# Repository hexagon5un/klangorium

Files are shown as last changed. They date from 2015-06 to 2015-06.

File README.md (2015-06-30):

# The Klangorium
Hardware and tutorials for the Hackaday / Logic Noise Klangorium demo board

Over on [Hackaday](https://www.hackaday.com), I've been writing a [series of articles](https://hackaday.com/tag/logic-noise/) on building up synthesizers out of 4000-series CMOS logic chips.  It's been great fun building them up on an breadboard and then tearing them back down, but after a while it's time to do something more permanent.

The result is this here Klangorium board.  

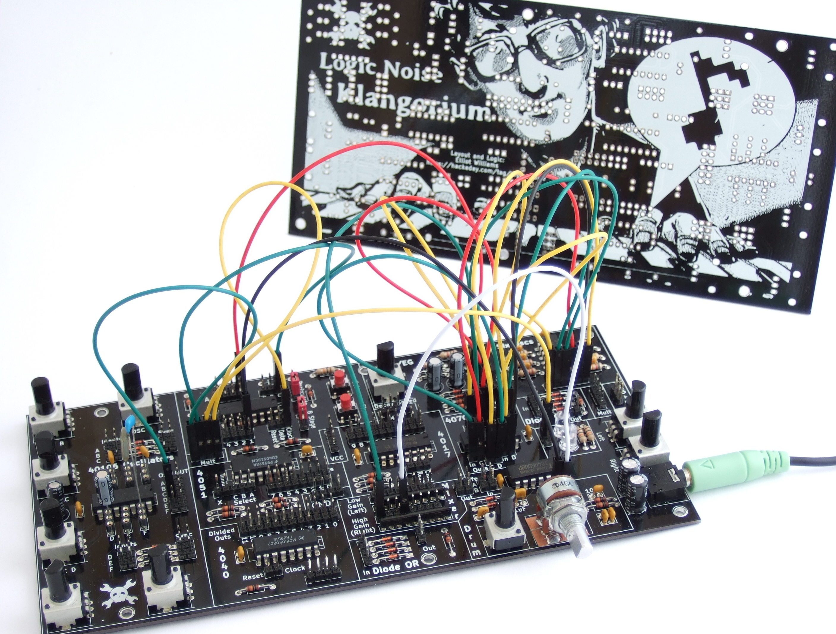
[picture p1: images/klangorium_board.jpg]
Board Money Shot


For a tutorial on how to use it, please head over to the [Hackaday.io](https://hackaday.io/project/6540-logic-noise-klangorium) page, or just start working through the [Logic Noise series](https://hackaday.com/tag/logic-noise/) from the beginning.  You'll find that it covers one module per session, and you'll learn a hell of a lot about ghetto synthesis and logic chips if you do.

## Getting One 

If you just want one, and can't wait for it to show up in kit form in the Hackaday shop, the production gerbers of version 1.0 are all zipped up [here](https://github.com/hexagon5un/klangorium/blob/master/kicad/gerbers/logic_noise_playground_elliot_williams.zip).  They're guaranteed to work with Elecrow, and will probably work for any other board manufacturer that's able to change the filename extensions if they need to.  

If you'd like to make your own, the design is entirely possible to do at home.  (I should know, I've built a couple prototypes.)  It's in Kicad, and designed with 16 mil traces and spacing, which is totally doable by toner transfer.  The only trick is that it's double-sided, but all you really have to do there is get the alignment right and pay attention to soldering the pin-headers to the top side when necessary.  And then drill something like 550 holes...  You probably want to get this one fabbed or wait until we have them for sale.

And if you'd just like to mess around with some of the circuit ideas, the kicad directory is for you!  The project is structured as a heirarchical schematic, and each module sits inside its own sub-sheet.  So if you just want the VCA/EG part of the board for a project of yours, it's in vca_eg.sch.  How easy is that?!

## Building One

Say you've got the board and parts in front of you.  Congrats!  Now put it together. 

It's not hard, but it's got 550 solder joints.  The good news is that none of them are particularly critical or difficult.  If you're a beginner with the soldering iron, you'll be experienced by the time you're done.  (Or you'll be driven stark-raving mad.)

I've built up a few of these now, and here's my advice.  

First, put all the header pins in their respective holes.  Now get a piece of cardboard and put it on top of the pins before you (gently) flip it over.  This way, you stand a chance of getting the pins aligned straight with the board upside-down.  Now solder in one pin from each header, to make it easy to adjust any that are screwy.  Only once you're content that they're all in straight, solder the headers in for real.  It's a lot of soldering.  Take a break.

Now you've got a lot of freedom of choice.  I'd start by completely populating and soldering the mixer/output section and then the six oscillators at the far left of the board.  You can have a lot of fun with just six voices.  See [the first Logic Noise column](https://hackaday.com/2015/02/04/logic-noise-sweet-sweet-oscillator-sounds/) for inspiration. 

And then keep following through the series, building out a new module one at a time and then working through the examples and playing around until you've got mastery of the parts.  I wrote the columns to build on each other, so if you follow along, you'll always have what you need for any of the examples already built up from previous columns.  

By the time you come to the end, you've reached Nirvana.  If you haven't had fun with the sequencer and Melody Generator circuits, I don't know what to say.  

And if you do pick this up and enjoy, let me know?

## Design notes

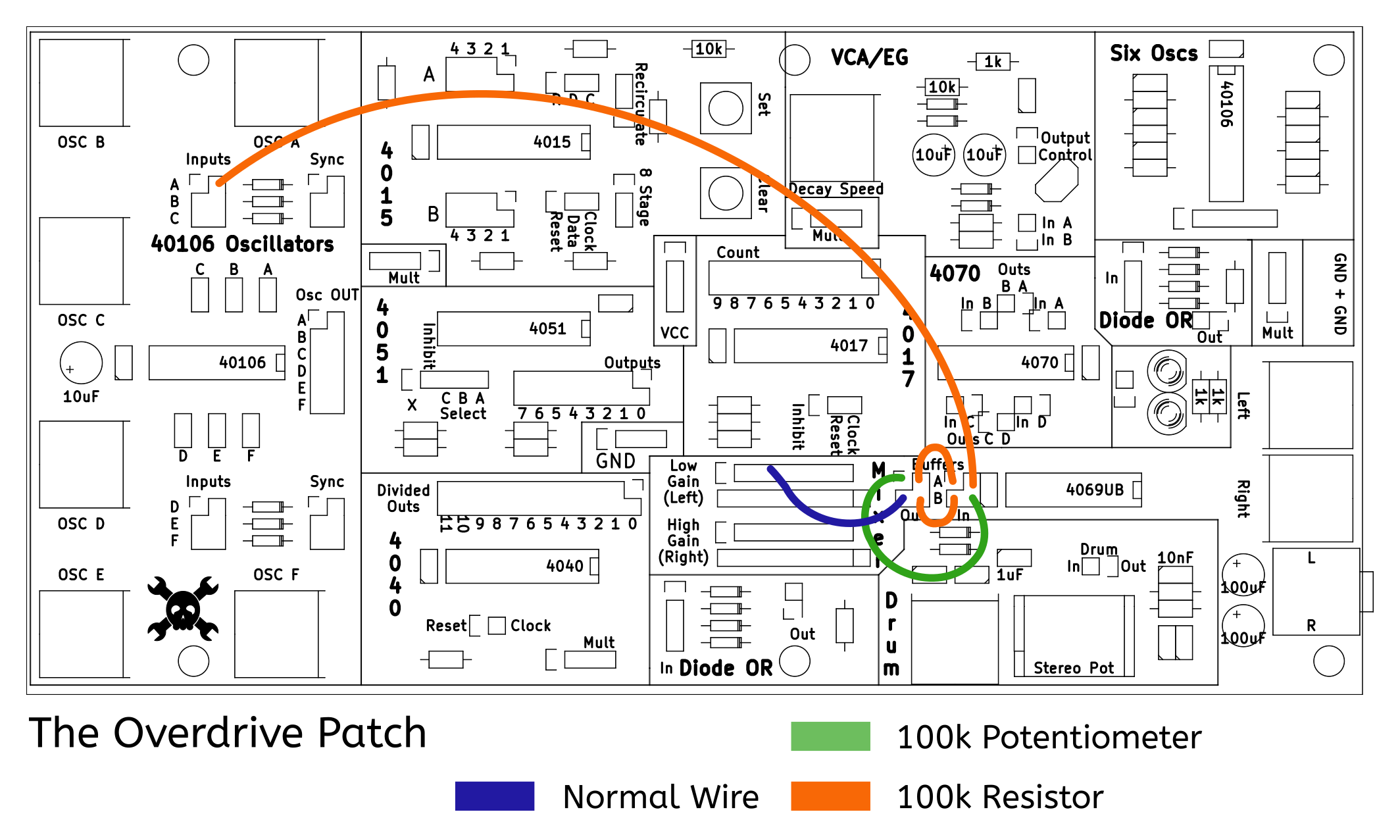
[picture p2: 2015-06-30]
images/patch_overdrive.png

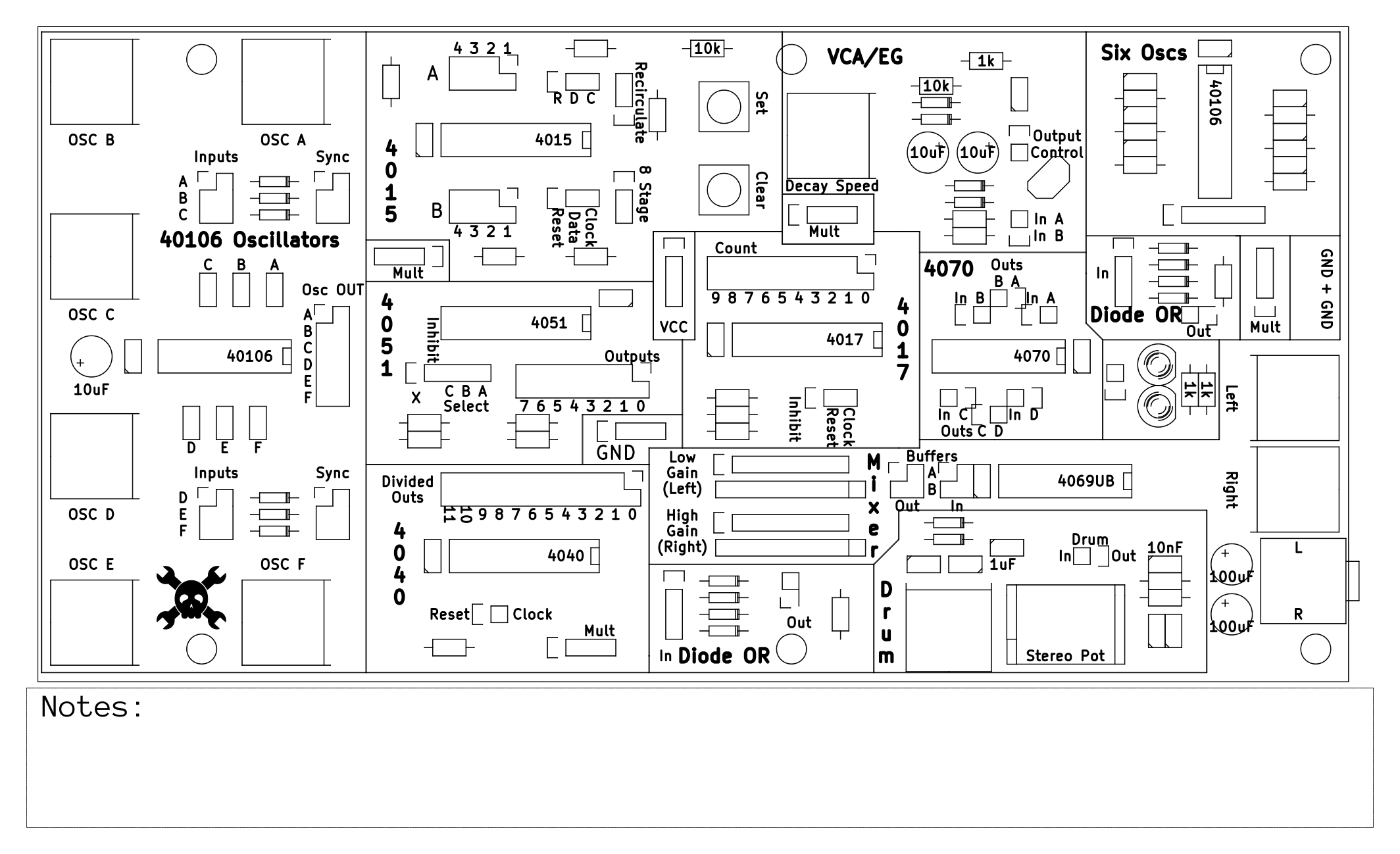
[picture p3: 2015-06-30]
images/patch_template.png

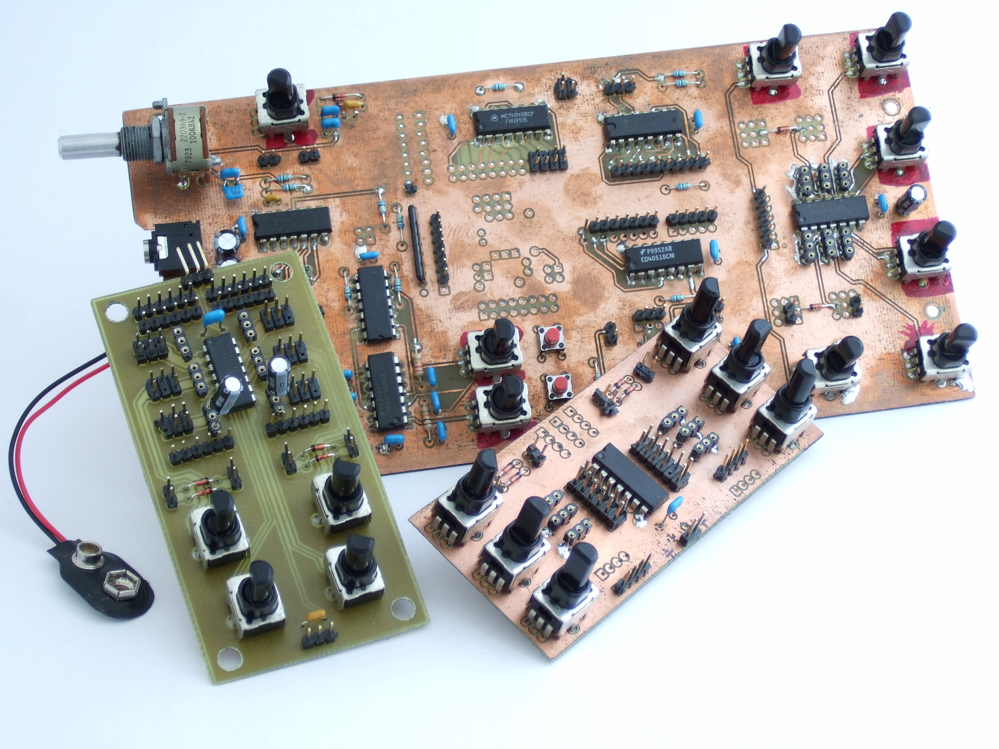
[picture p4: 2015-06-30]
images/klangorium_prototypes.jpg

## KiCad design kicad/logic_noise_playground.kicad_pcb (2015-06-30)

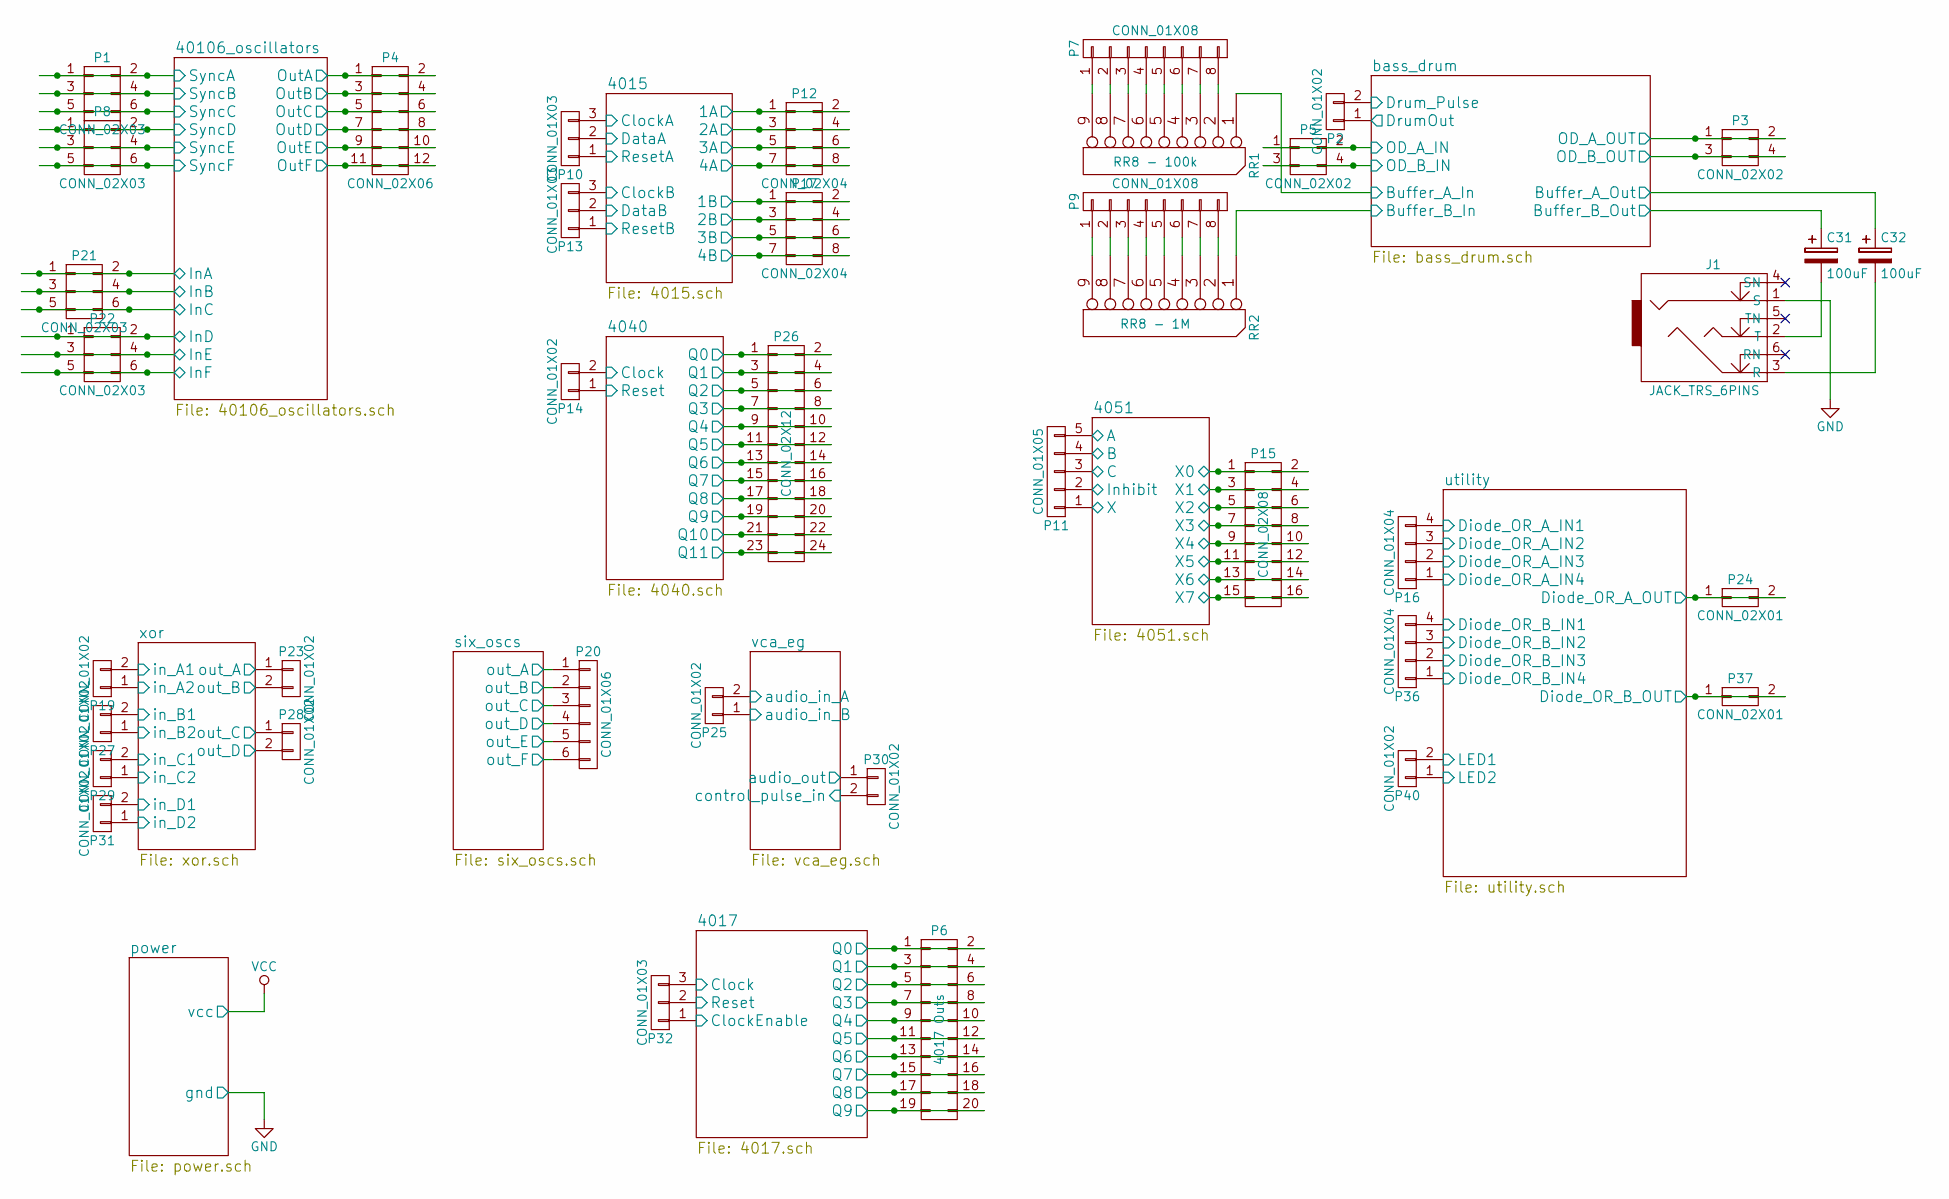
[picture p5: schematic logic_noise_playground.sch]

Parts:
C31, C32: 100uF; Elko_vert_11.2x6.3mm_RM2.5
J1: JACK_TRS_6PINS; stereo_jack
P1, P8, P21, P22: CONN_02X03; Pin_Header_Straight_2x03
P2, P14, P19, P23, P25, P27, P28, P29, P30, P31, P40: CONN_01X02; Pin_Header_Straight_1x02
P3, P5: CONN_02X02; Pin_Header_Straight_2x02
P4: CONN_02X06; Pin_Header_Straight_2x06
P6: 4017 Outs; Pin_Header_Straight_2x10
P7, P9: CONN_01X08; Pin_Header_Straight_1x08
P10, P13, P32: CONN_01X03; Pin_Header_Straight_1x03
P11: CONN_01X05; Pin_Header_Straight_1x05
P12, P17: CONN_02X04; Pin_Header_Straight_2x04
P15: CONN_02X08; Pin_Header_Straight_2x08
P16, P36: CONN_01X04; Pin_Header_Straight_1x04
P20: CONN_01X06; Pin_Header_Straight_1x06
P24, P37: CONN_02X01; Pin_Header_Straight_2x01
P26: CONN_02X12; Pin_Header_Straight_2x12
RR1: RR8 - 100k; r_pack8
RR2: RR8 - 1M; r_pack8

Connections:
/4015/1A: P12.1, P12.2; also elsewhere on the board
/4015/1B: P17.1, P17.2; also elsewhere on the board
/4015/2A: P12.3, P12.4; also elsewhere on the board
/4015/2B: P17.3, P17.4; also elsewhere on the board
/4015/3A: P12.5, P12.6; also elsewhere on the board
/4015/3B: P17.5, P17.6; also elsewhere on the board
/4015/4A: P12.7, P12.8; also elsewhere on the board
/4015/4B: P17.7, P17.8; also elsewhere on the board
/4015/ClockA: P10.3; also elsewhere on the board
/4015/ClockB: P13.3; also elsewhere on the board
/4015/DataA: P10.2; also elsewhere on the board
/4015/DataB: P13.2; also elsewhere on the board
/4015/ResetA: P10.1; also elsewhere on the board
/4015/ResetB: P13.1; also elsewhere on the board
/4017/Clock: P32.3; also elsewhere on the board
/4017/ClockEnable: P32.1; also elsewhere on the board
/4017/Q0: P6.1, P6.2; also elsewhere on the board
/4017/Q1: P6.3, P6.4; also elsewhere on the board
/4017/Q2: P6.5, P6.6; also elsewhere on the board
/4017/Q3: P6.7, P6.8; also elsewhere on the board
/4017/Q4: P6.9, P6.10; also elsewhere on the board
/4017/Q5: P6.11, P6.12; also elsewhere on the board
/4017/Q6: P6.13, P6.14; also elsewhere on the board
/4017/Q7: P6.15, P6.16; also elsewhere on the board
/4017/Q8: P6.17, P6.18; also elsewhere on the board
/4017/Q9: P6.19, P6.20; also elsewhere on the board
/4017/Reset: P32.2; also elsewhere on the board
/4040/Clock: P14.2; also elsewhere on the board
/4040/Q0: P26.1, P26.2; also elsewhere on the board
/4040/Q1: P26.3, P26.4; also elsewhere on the board
/4040/Q2: P26.5, P26.6; also elsewhere on the board
/4040/Q3: P26.7, P26.8; also elsewhere on the board
/4040/Q4: P26.9, P26.10; also elsewhere on the board
/4040/Q5: P26.11, P26.12; also elsewhere on the board
/4040/Q6: P26.13, P26.14; also elsewhere on the board
/4040/Q7: P26.15, P26.16; also elsewhere on the board
/4040/Q8: P26.17, P26.18; also elsewhere on the board
/4040/Q9: P26.19, P26.20; also elsewhere on the board
/4040/Q10: P26.21, P26.22; also elsewhere on the board
/4040/Q11: P26.23, P26.24; also elsewhere on the board
/4040/Reset: P14.1; also elsewhere on the board
/4051/A: P11.5; also elsewhere on the board
/4051/B: P11.4; also elsewhere on the board
/4051/C: P11.3; also elsewhere on the board
/4051/Inhibit: P11.2; also elsewhere on the board
/4051/X: P11.1; also elsewhere on the board
/4051/X0: P15.1, P15.2; also elsewhere on the board
/4051/X1: P15.3, P15.4; also elsewhere on the board
/4051/X2: P15.5, P15.6; also elsewhere on the board
/4051/X3: P15.7, P15.8; also elsewhere on the board
/4051/X4: P15.9, P15.10; also elsewhere on the board
/4051/X5: P15.11, P15.12; also elsewhere on the board
/4051/X6: P15.13, P15.14; also elsewhere on the board
/4051/X7: P15.15, P15.16; also elsewhere on the board
/40106_oscillators/InA: P21.1, P21.2; also elsewhere on the board
/40106_oscillators/InB: P21.3, P21.4; also elsewhere on the board
/40106_oscillators/InC: P21.5, P21.6; also elsewhere on the board
/40106_oscillators/InD: P22.1, P22.2; also elsewhere on the board
/40106_oscillators/InE: P22.3, P22.4; also elsewhere on the board
/40106_oscillators/InF: P22.5, P22.6; also elsewhere on the board
/40106_oscillators/OutA: P4.1, P4.2; also elsewhere on the board
/40106_oscillators/OutB: P4.3, P4.4; also elsewhere on the board
/40106_oscillators/OutC: P4.5, P4.6; also elsewhere on the board
/40106_oscillators/OutD: P4.7, P4.8; also elsewhere on the board
/40106_oscillators/OutE: P4.9, P4.10; also elsewhere on the board
/40106_oscillators/OutF: P4.11, P4.12; also elsewhere on the board
/40106_oscillators/SyncA: P1.1, P1.2; also elsewhere on the board
/40106_oscillators/SyncB: P1.3, P1.4; also elsewhere on the board
/40106_oscillators/SyncC: P1.5, P1.6; also elsewhere on the board
/40106_oscillators/SyncD: P8.1, P8.2; also elsewhere on the board
/40106_oscillators/SyncE: P8.3, P8.4; also elsewhere on the board
/40106_oscillators/SyncF: P8.5, P8.6; also elsewhere on the board
/bass_drum/Buffer_A_In: RR1.1 (COM); also elsewhere on the board
/bass_drum/Buffer_A_Out: C32.1; also elsewhere on the board
/bass_drum/Buffer_B_In: RR2.1 (COM); also elsewhere on the board
/bass_drum/Buffer_B_Out: C31.1; also elsewhere on the board
/bass_drum/DrumOut: P2.1; also elsewhere on the board
/bass_drum/Drum_Pulse: P2.2; also elsewhere on the board
/bass_drum/OD_A_IN: P5.1, P5.2; also elsewhere on the board
/bass_drum/OD_A_OUT: P3.1, P3.2; also elsewhere on the board
/bass_drum/OD_B_IN: P5.3, P5.4; also elsewhere on the board
/bass_drum/OD_B_OUT: P3.3, P3.4; also elsewhere on the board
/six_oscs/out_A: P20.1; also elsewhere on the board
/six_oscs/out_B: P20.2; also elsewhere on the board
/six_oscs/out_C: P20.3; also elsewhere on the board
/six_oscs/out_D: P20.4; also elsewhere on the board
/six_oscs/out_E: P20.5; also elsewhere on the board
/six_oscs/out_F: P20.6; also elsewhere on the board
/utility/Diode_OR_A_IN1: P16.4; also elsewhere on the board
/utility/Diode_OR_A_IN2: P16.3; also elsewhere on the board
/utility/Diode_OR_A_IN3: P16.2; also elsewhere on the board
/utility/Diode_OR_A_IN4: P16.1; also elsewhere on the board
/utility/Diode_OR_A_OUT: P24.1, P24.2; also elsewhere on the board
/utility/Diode_OR_B_IN1: P36.4; also elsewhere on the board
/utility/Diode_OR_B_IN2: P36.3; also elsewhere on the board
/utility/Diode_OR_B_IN3: P36.2; also elsewhere on the board
/utility/Diode_OR_B_IN4: P36.1; also elsewhere on the board
/utility/Diode_OR_B_OUT: P37.1, P37.2; also elsewhere on the board
/utility/LED1: P40.2; also elsewhere on the board
/utility/LED2: P40.1; also elsewhere on the board
/vca_eg/audio_in_A: P25.2; also elsewhere on the board
/vca_eg/audio_in_B: P25.1; also elsewhere on the board
/vca_eg/audio_out: P30.1; also elsewhere on the board
/vca_eg/control_pulse_in: P30.2; also elsewhere on the board
/xor/in_A1: P19.2; also elsewhere on the board
/xor/in_A2: P19.1; also elsewhere on the board
/xor/in_B1: P27.2; also elsewhere on the board
/xor/in_B2: P27.1; also elsewhere on the board
/xor/in_C1: P29.2; also elsewhere on the board
/xor/in_C2: P29.1; also elsewhere on the board
/xor/in_D1: P31.2; also elsewhere on the board
/xor/in_D2: P31.1; also elsewhere on the board
/xor/out_A: P23.1; also elsewhere on the board
/xor/out_B: P23.2; also elsewhere on the board
/xor/out_C: P28.1; also elsewhere on the board
/xor/out_D: P28.2; also elsewhere on the board
GND: J1.1 (S); also elsewhere on the board
unnamed: C31.2, J1.2 (T)
unnamed: C32.2, J1.3 (R)
unnamed: P7.1, RR1.9
unnamed: P7.2, RR1.8
unnamed: P7.3, RR1.7
unnamed: P7.4, RR1.6
unnamed: P7.5, RR1.5
unnamed: P7.6, RR1.4
unnamed: P7.7, RR1.3
unnamed: P7.8, RR1.2
unnamed: P9.1, RR2.9
unnamed: P9.2, RR2.8
unnamed: P9.3, RR2.7
unnamed: P9.4, RR2.6
unnamed: P9.5, RR2.5
unnamed: P9.6, RR2.4
unnamed: P9.7, RR2.3
unnamed: P9.8, RR2.2

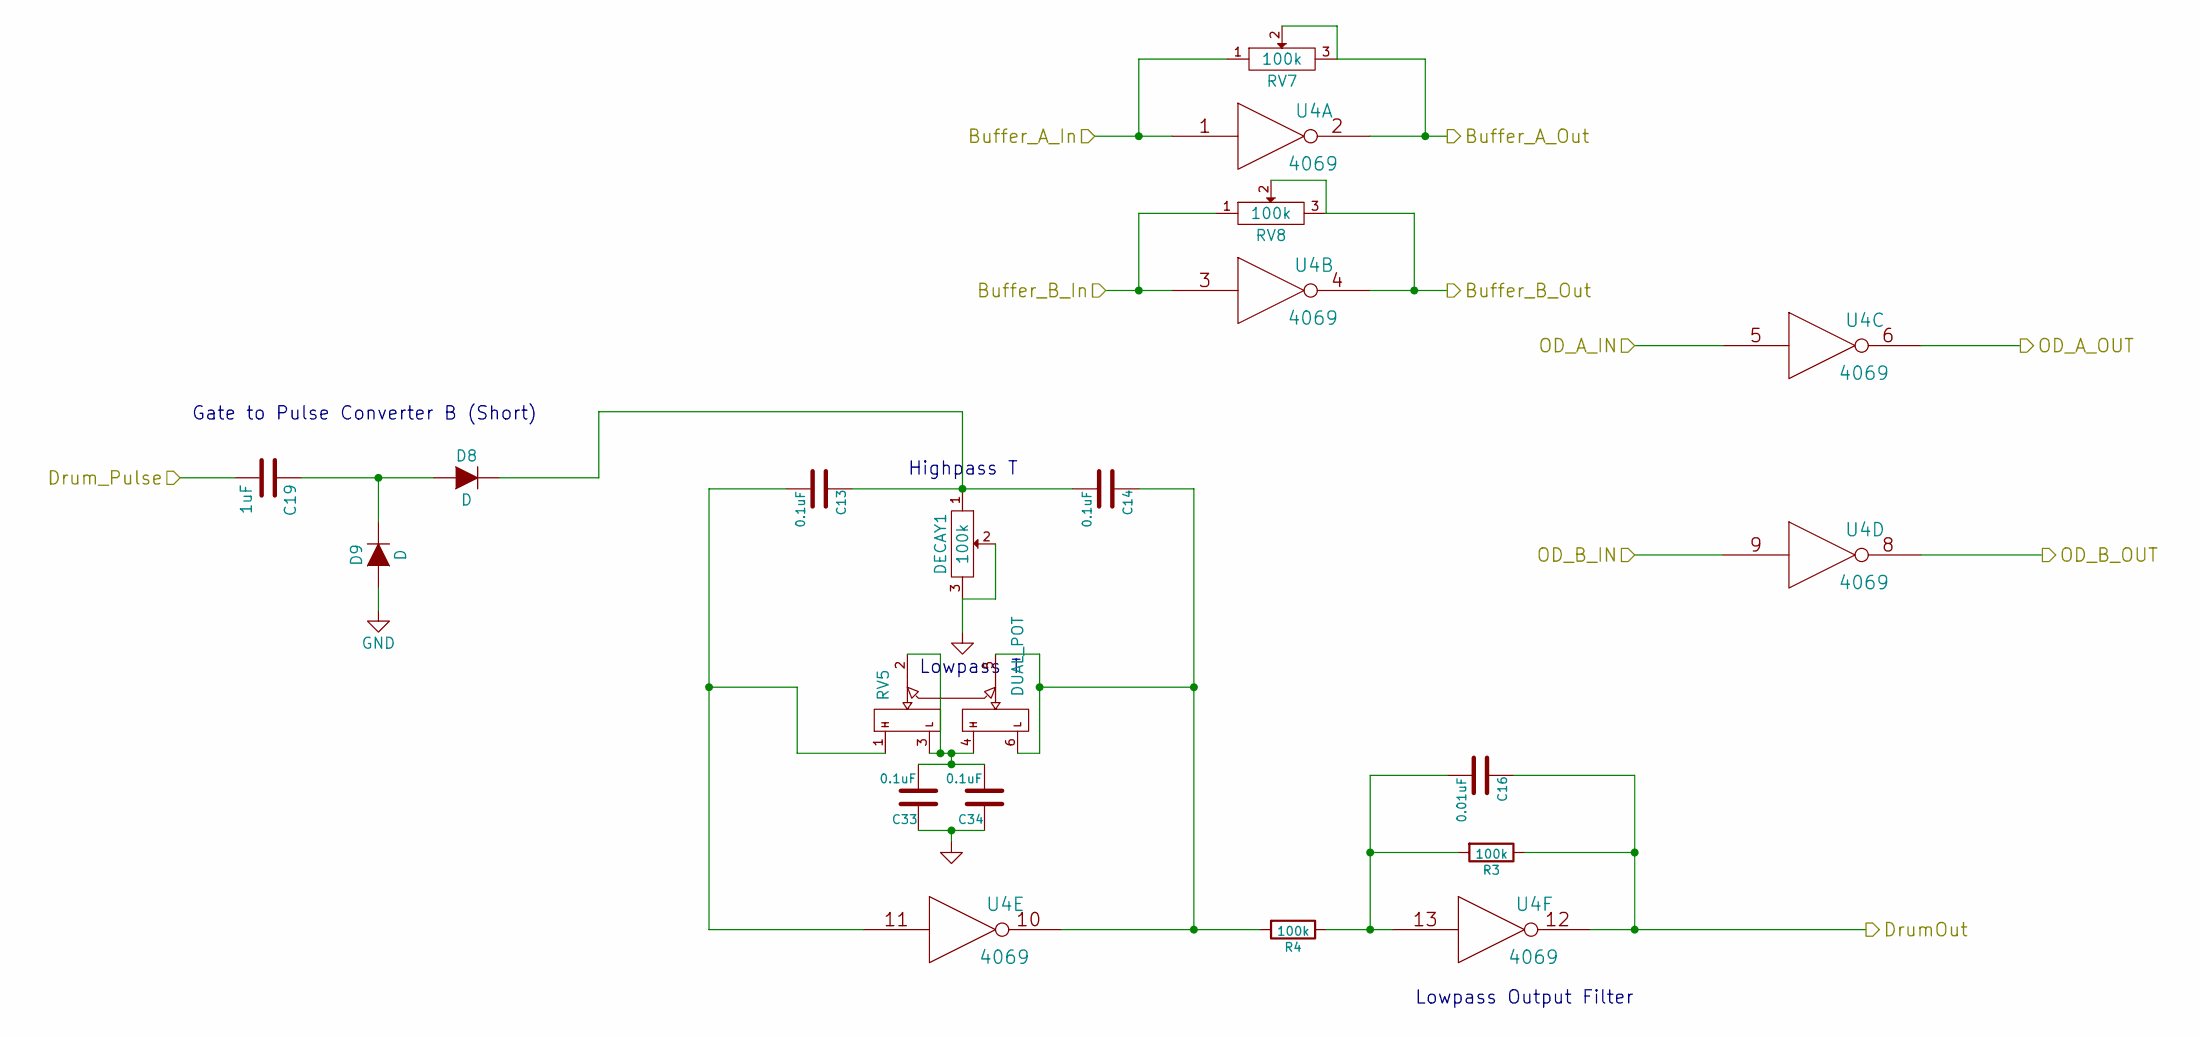
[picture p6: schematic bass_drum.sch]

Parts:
C13, C14, C33, C34: 0.1uF; C1
C16: 0.01uF; C1
C19: 1uF; C1
D8, D9: D; Diode_DO-35_SOD27_Horizontal_RM10
DECAY1: 100k; Potentiometer_9mm_vertical_pcb_mount
R3, R4: 100k; Resistor_Horizontal_RM10mm
RV5: DUAL_POT; Potentiometer_Alps-RK16-double
RV7, RV8: 100k; Potentiometer_9mm_vertical_pcb_mount
U4: 4069; DIP-14__300_ELL

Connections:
/bass_drum/Buffer_A_In: RV7.1, U4.1; also elsewhere on the board
/bass_drum/Buffer_A_Out: RV7.2, RV7.3, U4.2; also elsewhere on the board
/bass_drum/Buffer_B_In: RV8.1, U4.3; also elsewhere on the board
/bass_drum/Buffer_B_Out: RV8.2, RV8.3, U4.4; also elsewhere on the board
/bass_drum/DrumOut: C16.1, R3.1, U4.12; also elsewhere on the board
/bass_drum/Drum_Pulse: C19.2; also elsewhere on the board
/bass_drum/OD_A_IN: U4.5; also elsewhere on the board
/bass_drum/OD_A_OUT: U4.6; also elsewhere on the board
/bass_drum/OD_B_IN: U4.9; also elsewhere on the board
/bass_drum/OD_B_OUT: U4.8; also elsewhere on the board
GND: C33.1, C34.1, D9.1 (A), DECAY1.2, DECAY1.3, U4.7 (VSS); also elsewhere on the board
unnamed: C13.1, C14.2, D8.2 (K), DECAY1.1
unnamed: C13.2, RV5.1, U4.11
unnamed: C14.1, R4.2, RV5.5, RV5.6, U4.10
unnamed: C16.2, R3.2, R4.1, U4.13
unnamed: C19.1, D8.1 (A), D9.2 (K)
unnamed: C33.2, C34.2, RV5.2, RV5.3, RV5.4
VCC: U4.14 (VDD); also elsewhere on the board

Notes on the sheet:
Lowpass Output Filter
Highpass T
Lowpass T
Gate to Pulse Converter B (Short)

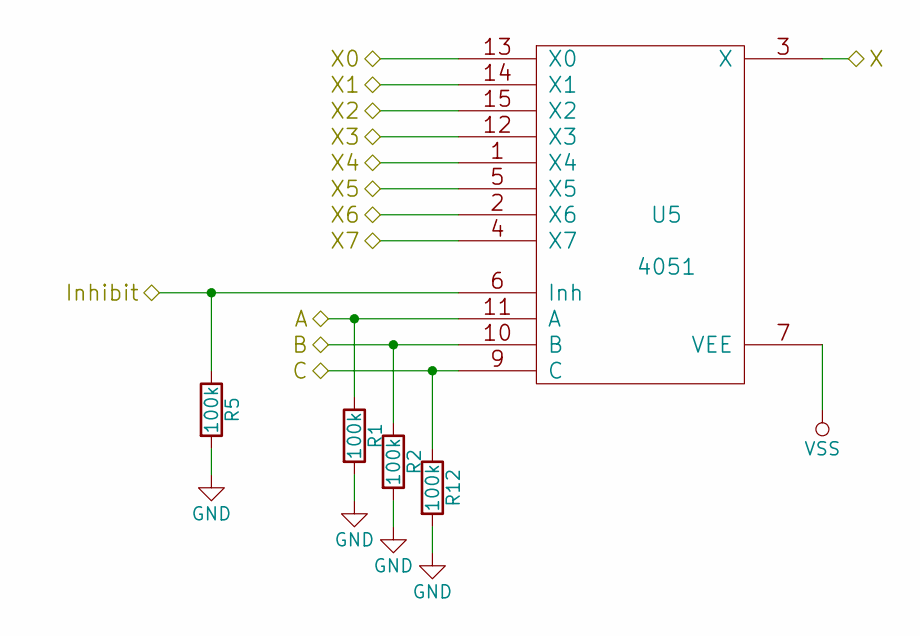
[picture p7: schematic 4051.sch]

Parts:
R1, R2, R5, R12: 100k; Resistor_Horizontal_RM10mm
U5: 4051; DIP-16__300_ELL

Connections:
/4051/A: R1.1, U5.11 (A); also elsewhere on the board
/4051/B: R2.1, U5.10 (B); also elsewhere on the board
/4051/C: R12.1, U5.9 (C); also elsewhere on the board
/4051/Inhibit: R5.1, U5.6 (Inh); also elsewhere on the board
/4051/X: U5.3 (X); also elsewhere on the board
/4051/X0: U5.13 (X0); also elsewhere on the board
/4051/X1: U5.14 (X1); also elsewhere on the board
/4051/X2: U5.15 (X2); also elsewhere on the board
/4051/X3: U5.12 (X3); also elsewhere on the board
/4051/X4: U5.1 (X4); also elsewhere on the board
/4051/X5: U5.5 (X5); also elsewhere on the board
/4051/X6: U5.2 (X6); also elsewhere on the board
/4051/X7: U5.4 (X7); also elsewhere on the board
GND: R1.2, R2.2, R5.2, R12.2, U5.7 (VEE), U5.8 (VSS); also elsewhere on the board
VCC: U5.16 (VDD); also elsewhere on the board

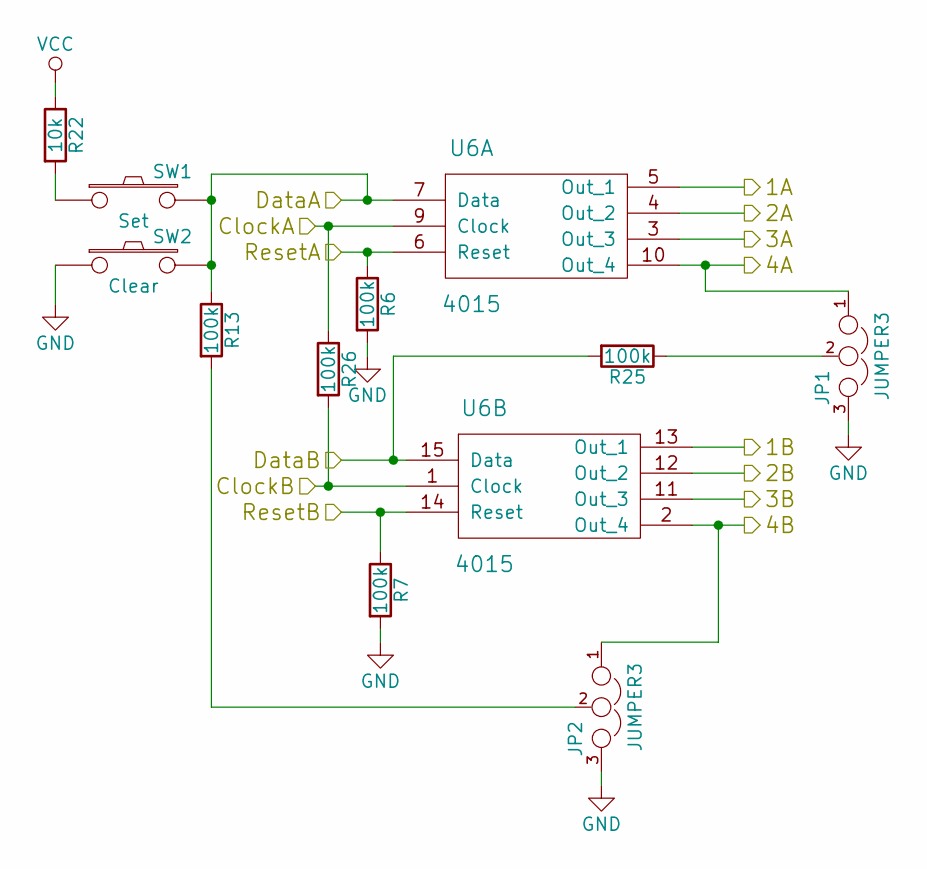
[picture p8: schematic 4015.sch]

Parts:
JP1, JP2: JUMPER3; Socket_Strip_Straight_1x03
R6, R7, R13, R25, R26: 100k; Resistor_Horizontal_RM10mm
R22: 10k; Resistor_Horizontal_RM10mm
SW1: Set; SW_PUSH_SMALL
SW2: Clear; SW_PUSH_SMALL
U6: 4015; DIP-16__300_ELL

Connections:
/4015/1A: U6.5 (Out_1); also elsewhere on the board
/4015/1B: U6.13 (Out_1); also elsewhere on the board
/4015/2A: U6.4 (Out_2); also elsewhere on the board
/4015/2B: U6.12 (Out_2); also elsewhere on the board
/4015/3A: U6.3 (Out_3); also elsewhere on the board
/4015/3B: U6.11 (Out_3); also elsewhere on the board
/4015/4A: JP1.1, U6.10 (Out_4); also elsewhere on the board
/4015/4B: JP2.1, U6.2 (Out_4); also elsewhere on the board
/4015/ClockA: R26.1, U6.9 (Clock); also elsewhere on the board
/4015/ClockB: R26.2, U6.1 (Clock); also elsewhere on the board
/4015/DataA: R13.1, SW1.2, SW2.2, U6.7 (Data); also elsewhere on the board
/4015/DataB: R25.2, U6.15 (Data); also elsewhere on the board
/4015/ResetA: R6.1, U6.6 (Reset); also elsewhere on the board
/4015/ResetB: R7.1, U6.14 (Reset); also elsewhere on the board
GND: JP1.3, JP2.3, R6.2, R7.2, SW2.1, U6.8 (VSS); also elsewhere on the board
unnamed: JP1.2, R25.1
unnamed: JP2.2, R13.2
unnamed: R22.2, SW1.1
VCC: R22.1, U6.16 (VDD); also elsewhere on the board

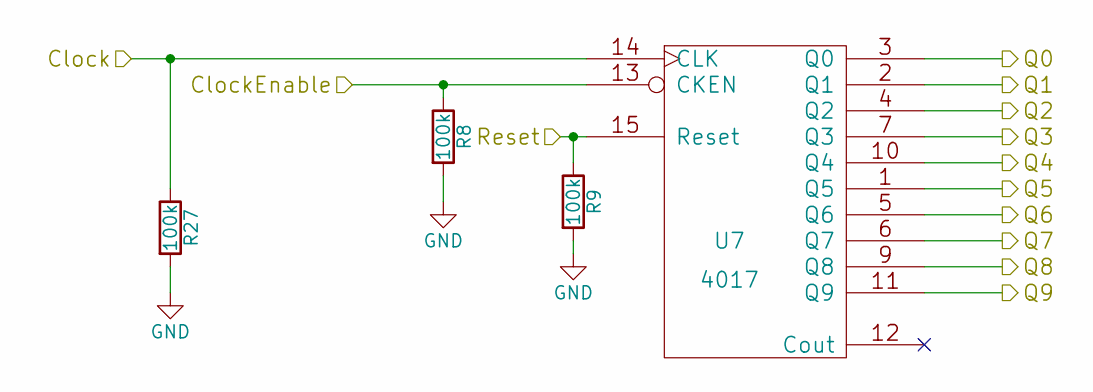
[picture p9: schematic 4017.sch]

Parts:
R8, R9, R27: 100k; Resistor_Horizontal_RM10mm
U7: 4017; DIP-16__300_ELL

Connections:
/4017/Clock: R27.1, U7.14 (CLK); also elsewhere on the board
/4017/ClockEnable: R8.1, U7.13 (CKEN); also elsewhere on the board
/4017/Q0: U7.3 (Q0); also elsewhere on the board
/4017/Q1: U7.2 (Q1); also elsewhere on the board
/4017/Q2: U7.4 (Q2); also elsewhere on the board
/4017/Q3: U7.7 (Q3); also elsewhere on the board
/4017/Q4: U7.10 (Q4); also elsewhere on the board
/4017/Q5: U7.1 (Q5); also elsewhere on the board
/4017/Q6: U7.5 (Q6); also elsewhere on the board
/4017/Q7: U7.6 (Q7); also elsewhere on the board
/4017/Q8: U7.9 (Q8); also elsewhere on the board
/4017/Q9: U7.11 (Q9); also elsewhere on the board
/4017/Reset: R9.1, U7.15 (Reset); also elsewhere on the board
GND: R8.2, R9.2, R27.2, U7.8 (VSS); also elsewhere on the board
VCC: U7.16 (VDD); also elsewhere on the board

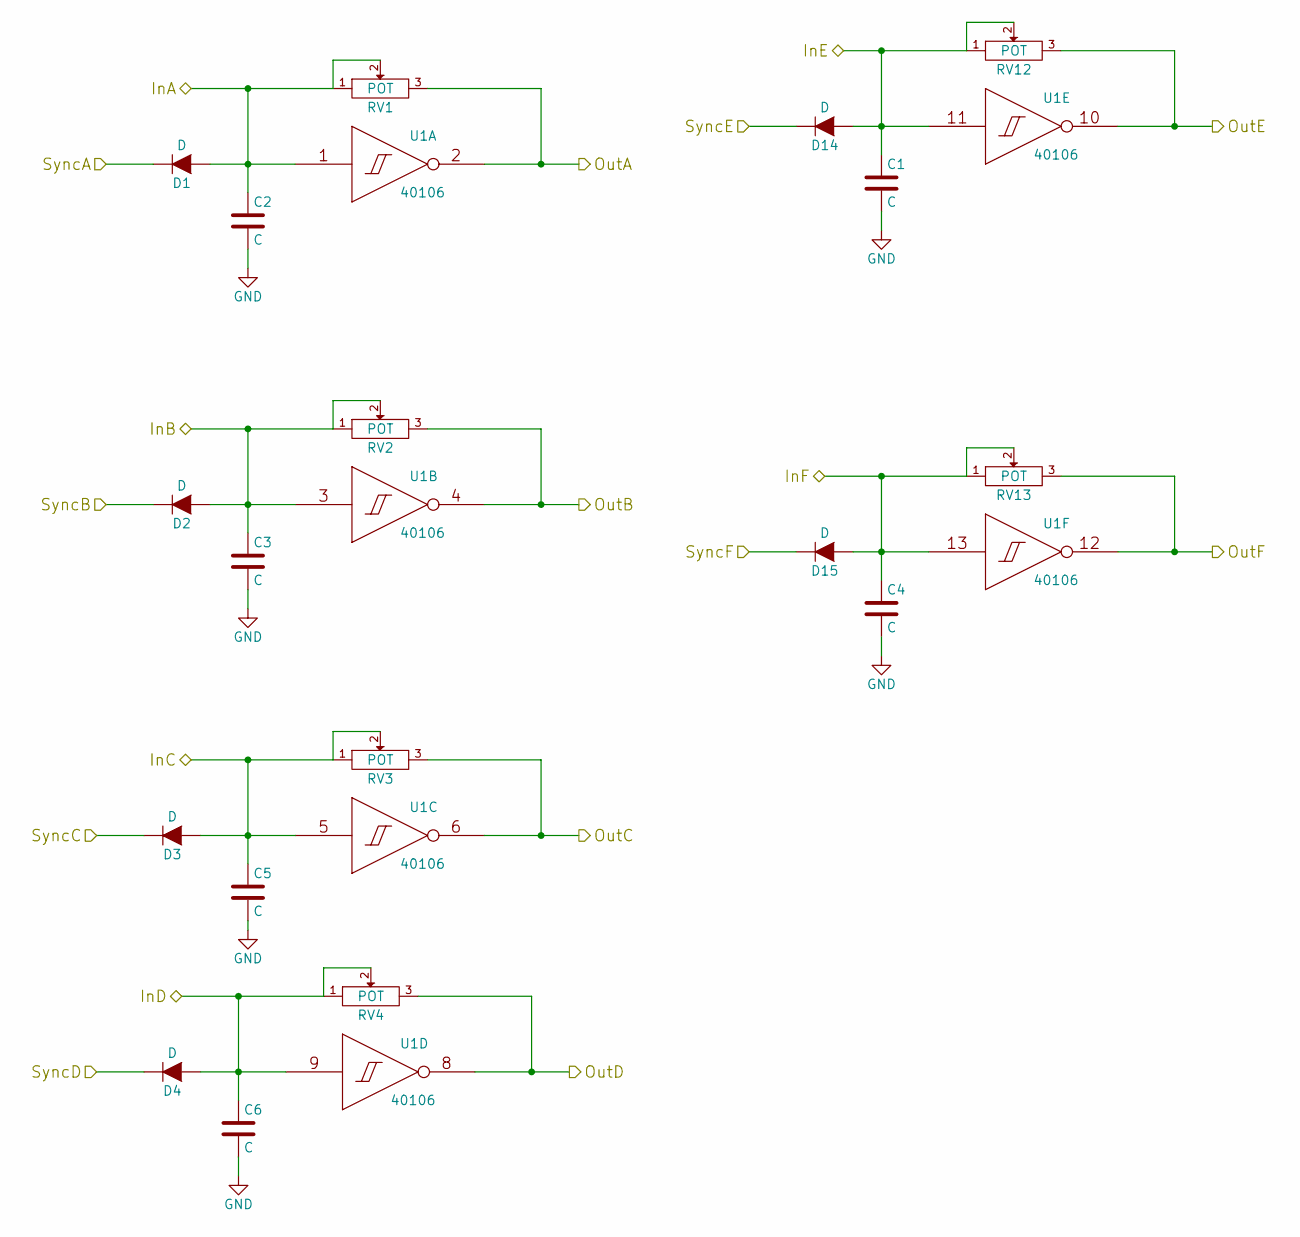
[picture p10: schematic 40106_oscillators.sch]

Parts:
C1, C2, C3, C4, C5, C6: C; cap_2+3
D1, D2, D3, D4, D14, D15: D; Diode_DO-35_SOD27_Horizontal_RM10
RV1, RV2, RV3, RV4, RV12, RV13: POT; Potentiometer_9mm_vertical_pcb_mount
U1: 40106; DIP-14__300_ELL

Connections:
/40106_oscillators/InA: C2.1, D1.1 (A), RV1.1, RV1.2, U1.1 (In); also elsewhere on the board
/40106_oscillators/InB: C3.1, D2.1 (A), RV2.1, RV2.2, U1.3 (In); also elsewhere on the board
/40106_oscillators/InC: C5.1, D3.1 (A), RV3.1, RV3.2, U1.5 (In); also elsewhere on the board
/40106_oscillators/InD: C6.1, D4.1 (A), RV4.1, RV4.2, U1.9 (In); also elsewhere on the board
/40106_oscillators/InE: C1.1, D14.1 (A), RV12.1, RV12.2, U1.11 (In); also elsewhere on the board
/40106_oscillators/InF: C4.1, D15.1 (A), RV13.1, RV13.2, U1.13 (In); also elsewhere on the board
/40106_oscillators/OutA: RV1.3, U1.2 (Out); also elsewhere on the board
/40106_oscillators/OutB: RV2.3, U1.4 (Out); also elsewhere on the board
/40106_oscillators/OutC: RV3.3, U1.6 (Out); also elsewhere on the board
/40106_oscillators/OutD: RV4.3, U1.8 (Out); also elsewhere on the board
/40106_oscillators/OutE: RV12.3, U1.10 (Out); also elsewhere on the board
/40106_oscillators/OutF: RV13.3, U1.12 (Out); also elsewhere on the board
/40106_oscillators/SyncA: D1.2 (K); also elsewhere on the board
/40106_oscillators/SyncB: D2.2 (K); also elsewhere on the board
/40106_oscillators/SyncC: D3.2 (K); also elsewhere on the board
/40106_oscillators/SyncD: D4.2 (K); also elsewhere on the board
/40106_oscillators/SyncE: D14.2 (K); also elsewhere on the board
/40106_oscillators/SyncF: D15.2 (K); also elsewhere on the board
GND: C1.2, C2.2, C3.2, C4.2, C5.2, C6.2, U1.7 (VSS); also elsewhere on the board
VCC: U1.14 (VDD); also elsewhere on the board

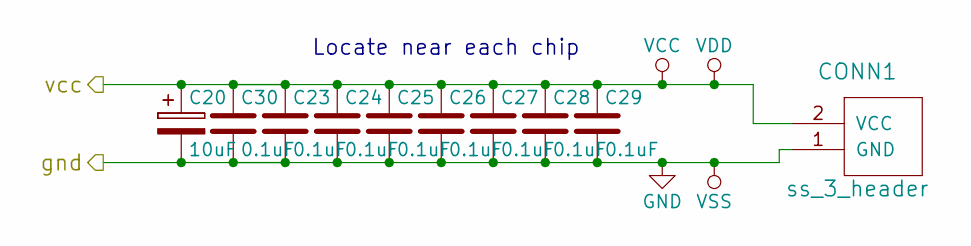
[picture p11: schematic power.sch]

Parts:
C20: 10uF; Elko_vert_11.2x6.3mm_RM2.5
C23, C24, C25, C26, C27, C28, C29, C30: 0.1uF; C1
CONN1: ss_3_header; connector_ss_3pin

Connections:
GND: C20.2, C23.2, C24.2, C25.2, C26.2, C27.2, C28.2, C29.2, C30.2, CONN1.1 (GND); also elsewhere on the board
VCC: C20.1, C23.1, C24.1, C25.1, C26.1, C27.1, C28.1, C29.1, C30.1, CONN1.2 (VCC); also elsewhere on the board

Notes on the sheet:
Locate near each chip

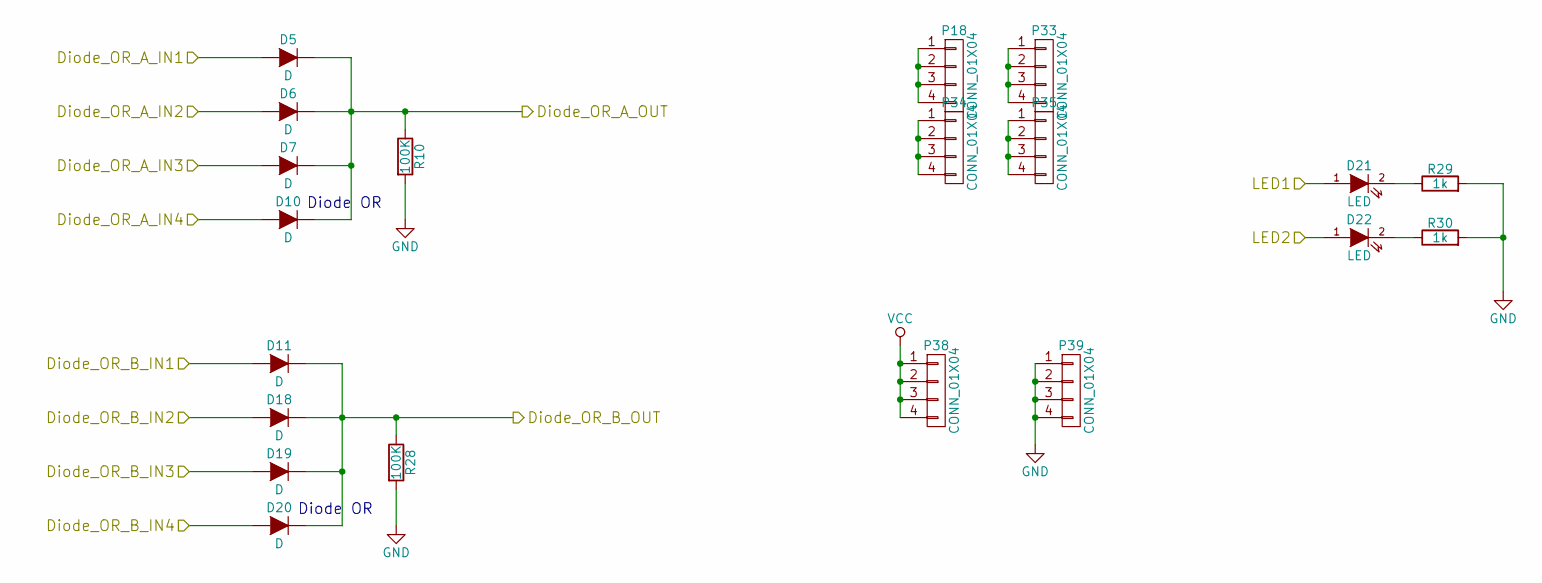
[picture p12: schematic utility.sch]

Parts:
D5, D6, D7, D10, D11, D18, D19, D20: D; Diode_DO-35_SOD27_Horizontal_RM10
D21, D22: LED; LED-5MM
P18, P33, P34, P35, P38, P39: CONN_01X04; Pin_Header_Straight_1x04
R10, R28: 100K; Resistor_Horizontal_RM10mm
R29, R30: 1k; Resistor_Horizontal_RM10mm

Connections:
/utility/Diode_OR_A_IN1: D5.1 (A); also elsewhere on the board
/utility/Diode_OR_A_IN2: D6.1 (A); also elsewhere on the board
/utility/Diode_OR_A_IN3: D7.1 (A); also elsewhere on the board
/utility/Diode_OR_A_IN4: D10.1 (A); also elsewhere on the board
/utility/Diode_OR_A_OUT: D5.2 (K), D6.2 (K), D7.2 (K), D10.2 (K), R10.1; also elsewhere on the board
/utility/Diode_OR_B_IN1: D11.1 (A); also elsewhere on the board
/utility/Diode_OR_B_IN2: D18.1 (A); also elsewhere on the board
/utility/Diode_OR_B_IN3: D19.1 (A); also elsewhere on the board
/utility/Diode_OR_B_IN4: D20.1 (A); also elsewhere on the board
/utility/Diode_OR_B_OUT: D11.2 (K), D18.2 (K), D19.2 (K), D20.2 (K), R28.1; also elsewhere on the board
/utility/LED1: D21.1 (A); also elsewhere on the board
/utility/LED2: D22.1 (A); also elsewhere on the board
GND: P39.1, P39.2, P39.3, P39.4, R10.2, R28.2, R29.2, R30.2; also elsewhere on the board
unnamed: D21.2 (K), R29.1
unnamed: D22.2 (K), R30.1
unnamed: P18.1, P18.2, P18.3, P18.4
unnamed: P33.1, P33.2, P33.3, P33.4
unnamed: P34.1, P34.2, P34.3, P34.4
unnamed: P35.1, P35.2, P35.3, P35.4
VCC: P38.1, P38.2, P38.3, P38.4; also elsewhere on the board

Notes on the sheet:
Diode OR

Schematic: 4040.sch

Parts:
R11: 100k; Resistor_Horizontal_RM10mm
U8: 4040; DIP-16__300_ELL

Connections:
/4040/Clock: U8.10 (CLK); also elsewhere on the board
/4040/Q0: U8.9 (Q0); also elsewhere on the board
/4040/Q1: U8.7 (Q1); also elsewhere on the board
/4040/Q2: U8.6 (Q2); also elsewhere on the board
/4040/Q3: U8.5 (Q3); also elsewhere on the board
/4040/Q4: U8.3 (Q4); also elsewhere on the board
/4040/Q5: U8.2 (Q5); also elsewhere on the board
/4040/Q6: U8.4 (Q6); also elsewhere on the board
/4040/Q7: U8.13 (Q7); also elsewhere on the board
/4040/Q8: U8.12 (Q8); also elsewhere on the board
/4040/Q9: U8.14 (Q9); also elsewhere on the board
/4040/Q10: U8.15 (Q10); also elsewhere on the board
/4040/Q11: U8.1 (Q11); also elsewhere on the board
/4040/Reset: R11.1, U8.11 (Reset); also elsewhere on the board
GND: R11.2, U8.8 (VSS); also elsewhere on the board
VCC: U8.16 (VDD); also elsewhere on the board

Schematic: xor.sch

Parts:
U2: 4070; DIP-14__300_ELL

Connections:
/xor/in_A1: U2.1; also elsewhere on the board
/xor/in_A2: U2.2; also elsewhere on the board
/xor/in_B1: U2.5; also elsewhere on the board
/xor/in_B2: U2.6; also elsewhere on the board
/xor/in_C1: U2.8; also elsewhere on the board
/xor/in_C2: U2.9; also elsewhere on the board
/xor/in_D1: U2.12; also elsewhere on the board
/xor/in_D2: U2.13; also elsewhere on the board
/xor/out_A: U2.3; also elsewhere on the board
/xor/out_B: U2.4; also elsewhere on the board
/xor/out_C: U2.10; also elsewhere on the board
/xor/out_D: U2.11; also elsewhere on the board
GND: U2.7 (VSS); also elsewhere on the board
VCC: U2.14 (VDD); also elsewhere on the board

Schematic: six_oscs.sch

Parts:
C7, C8, C9, C10, C11, C12: 0.1uF; C1
R14: 10k; Resistor_Horizontal_RM10mm
R15: 33k; Resistor_Horizontal_RM10mm
R16: 22k; Resistor_Horizontal_RM10mm
R17: 47k; Resistor_Horizontal_RM10mm
R18: 56k; Resistor_Horizontal_RM10mm
R19: 39k; Resistor_Horizontal_RM10mm
U3: 40106; DIP-14__300_ELL

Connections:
/six_oscs/out_A: R14.1, U3.2 (Out); also elsewhere on the board
/six_oscs/out_B: R15.1, U3.4 (Out); also elsewhere on the board
/six_oscs/out_C: R16.1, U3.6 (Out); also elsewhere on the board
/six_oscs/out_D: R17.1, U3.8 (Out); also elsewhere on the board
/six_oscs/out_E: R18.1, U3.10 (Out); also elsewhere on the board
/six_oscs/out_F: R19.1, U3.12 (Out); also elsewhere on the board
GND: C7.1, C8.1, C9.1, C10.1, C11.1, C12.1, U3.7 (VSS); also elsewhere on the board
unnamed: C7.2, R14.2, U3.1 (In)
unnamed: C8.2, R15.2, U3.3 (In)
unnamed: C9.2, R16.2, U3.5 (In)
unnamed: C10.2, R17.2, U3.9 (In)
unnamed: C11.2, R18.2, U3.11 (In)
unnamed: C12.2, R19.2, U3.13 (In)
VCC: U3.14 (VDD); also elsewhere on the board

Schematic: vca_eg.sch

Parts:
C15: 1uF; C1
C21, C22: 10uF; Elko_vert_11.2x6.3mm_RM2.5
D12, D13, D16, D17: D; Diode_DO-35_SOD27_Horizontal_RM10
Q1: LM3904; TO92
R20, R21: 100k; Resistor_Horizontal_RM10mm
R23: 10K; Resistor_Horizontal_RM10mm
R24: 1k; Resistor_Horizontal_RM10mm
RV6: POT; Potentiometer_9mm_vertical_pcb_mount

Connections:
/vca_eg/audio_in_A: R20.1; also elsewhere on the board
/vca_eg/audio_in_B: R21.2; also elsewhere on the board
/vca_eg/audio_out: C15.1; also elsewhere on the board
/vca_eg/control_pulse_in: C21.1; also elsewhere on the board
GND: C22.2, D17.1 (A), R24.2, RV6.2, RV6.3; also elsewhere on the board
unnamed: C15.2, Q1.3 (E), R24.1
unnamed: C21.2, D16.1 (A), D17.2 (K)
unnamed: C22.1, D16.2 (K), R23.2, RV6.1
unnamed: D12.1 (A), D13.1 (A), R23.1
unnamed: D12.2 (K), R20.2, R21.1
unnamed: D13.2 (K), Q1.2 (B)
VCC: Q1.1 (C); also elsewhere on the board

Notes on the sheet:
Gate to Pulse Converter A (Long)
VCA_A
pol caps

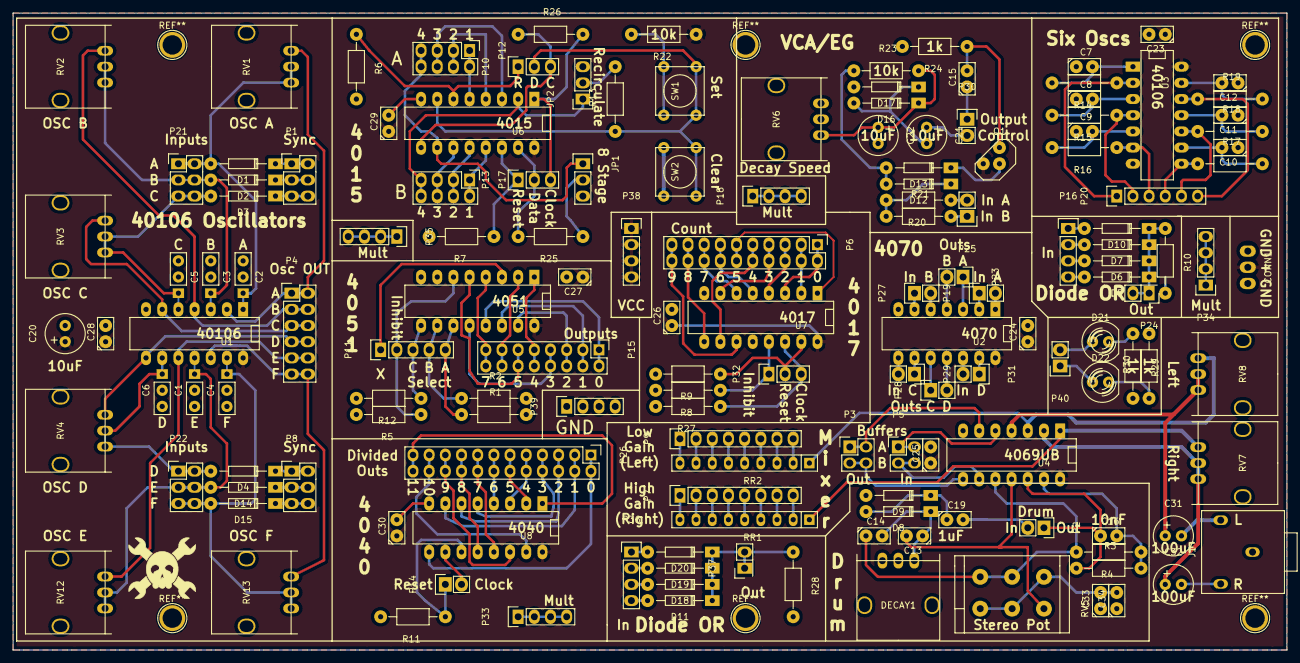
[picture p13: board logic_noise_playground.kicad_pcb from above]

Board: 2 copper layers, 200.0 x 100.0 mm, 152 parts (0 on the bottom side), 163 nets.

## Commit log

2015-06-30 Initial commit
    This is version 1.0 of the board
    Working on filling out tutorials.
    [40106_oscillators.sch, 4015.sch, 4017.sch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]
2015-06-30 Added the zip file with production Gerber files
    (This is what you submit to a board house to get these made)
